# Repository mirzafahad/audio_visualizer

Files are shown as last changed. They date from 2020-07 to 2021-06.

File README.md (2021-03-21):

# RGB LED Backlight and Audio Visualizer



:star: Star me on GitHub — it helps!

A simple WS2812 LED Strip based backlight and audio visualizer using [Adafruit nrf52832 Feather](https://www.adafruit.com/product/3406). You can control the color and modes using an Android App. 

More can be found [here](https://mirzafahad.github.io/2020-07-13-audio-visualizer/).

Backlight in action:  
Backlight in action

Motion Detection:  
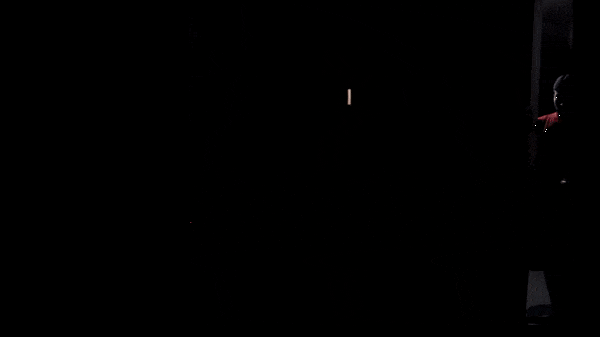
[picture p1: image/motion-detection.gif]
Motion Detection


Android App:  
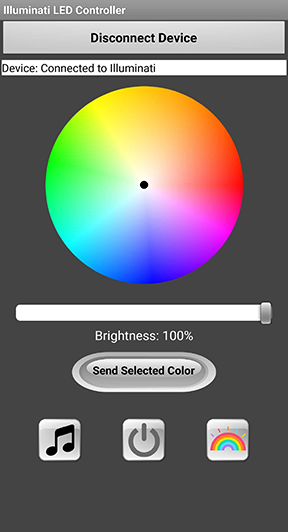
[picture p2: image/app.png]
App Interface


Hardware:  
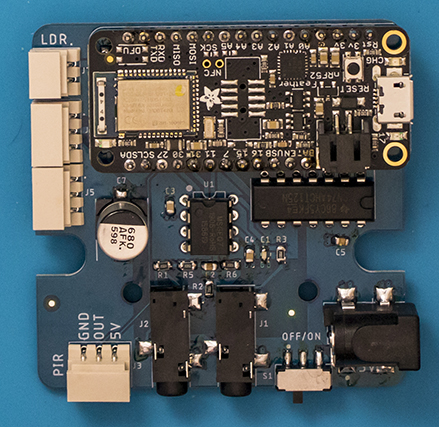
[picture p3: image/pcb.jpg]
Hardware


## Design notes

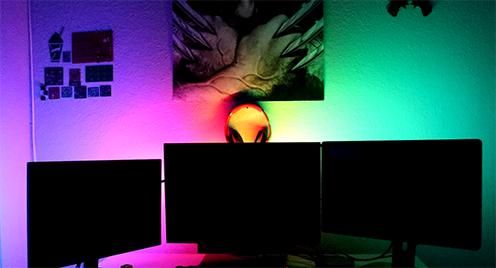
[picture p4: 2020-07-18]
image/demo.png

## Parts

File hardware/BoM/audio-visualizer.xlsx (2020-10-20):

Part | Value | Device | Package | Description
C1 | 33pF | CAP_0805 | CAP_CL21_SAM
C2 | 0.01uF | CAP_0805 | CAP_CL21_SAM
C3 | 1uF | CAP_0805 | CAP_CL21_SAM
C4 | 1uF | CAP_0805 | CAP_CL21_SAM
C5 | 1uF | CAP_0805 | CAP_CL21_SAM
C7 | 680uF | EEE-FK1A681P | CAPAE830X1050N | Cap Aluminum Lytic 680uF 10V 20% (8 X 10.2mm) SMD 600mA 2000h 105C Automotive T/R
J1 | SJ-3523-SMT-TR | SJ-3523-SMT-TR | SJ3523SMTTR | Phone Connectors Audio Jacks
J2 | SJ-3523-SMT-TR | SJ-3523-SMT-TR | SJ3523SMTTR | Phone Connectors Audio Jacks
J3 | 22057035 | 22057035 | 22057035 | Headers & Wire Housings SPOX .098 HDR 03P RA SN"
J4 | 22057035 | 22057035 | 22057035 | Headers & Wire Housings SPOX .098 HDR 03P RA SN"
J5 | 22057035 | 22057035 | 22057035 | Headers & Wire Housings SPOX .098 HDR 03P RA SN"
J6 | PJ-002AH-SMT-TR | PJ-002AH-SMT-TR | CUI_PJ-002AH-SMT-TR | 2.0 mm Center Pin, 5.0 A, Right Angle, Surface Mount (SMT), Dc Power Jack Connector Check prices
J7 | 22-05-7025 | 22-05-7025 | MOLEX_22-05-7025 | Connector Header Through Hole, Right Angle 2 position 0.098in (2.50mm) Buy Part
LOGO1 | OSHW-LOGOL-COPPER | OSHW-LOGOL-COPPER | OSHW-LOGO-L_COPPER | Open-Source Hardware (OSHW) Logo
MS1 | FEATHERWING_JUST_PINS | FEATHERWING_JUST_PINS | FEATHERWING_JUST_PINS
R1 | 10K | R-US_R0805 | R0805 | RESISTOR, American symbol
R2 | 10K | R-US_R0805 | R0805 | RESISTOR, American symbol
R3 | 200K | R-US_R0805 | R0805 | RESISTOR, American symbol
R4 | 330 | R-US_R0805 | R0805 | RESISTOR, American symbol
R5 | 10K | R-US_R0805 | R0805 | RESISTOR, American symbol
R6 | 10K | R-US_R0805 | R0805 | RESISTOR, American symbol
R8 | 10K | R-US_R0805 | R0805 | RESISTOR, American symbol
S1 | JS102011SAQN | JS102011SAQN | JS102011SAQN | C & K COMPONENTS - JS102011SAQN - SWITCH, SPDT, 0.6A, 6VDC, SIDE, SMD
U$2 | FIDUCIAL | FIDUCIAL | FIDUCIAL_1MM | For use by pick and place machines to calibrate the vision/machine, 1mm
U$3 | FIDUCIAL | FIDUCIAL | FIDUCIAL_1MM | For use by pick and place machines to calibrate the vision/machine, 1mm
U$4 | FIDUCIAL | FIDUCIAL | FIDUCIAL_1MM | For use by pick and place machines to calibrate the vision/machine, 1mm
U1 | MSGEQ7P | MSGEQ7DIL | DIP08 | 7-band graphic equalizer
U2 | SN74AHCT125N | SN74AHCT125N | DIP794W53P254L1930H508Q14N | Quadruple Bus Buffer Gates With 3-State Outputs

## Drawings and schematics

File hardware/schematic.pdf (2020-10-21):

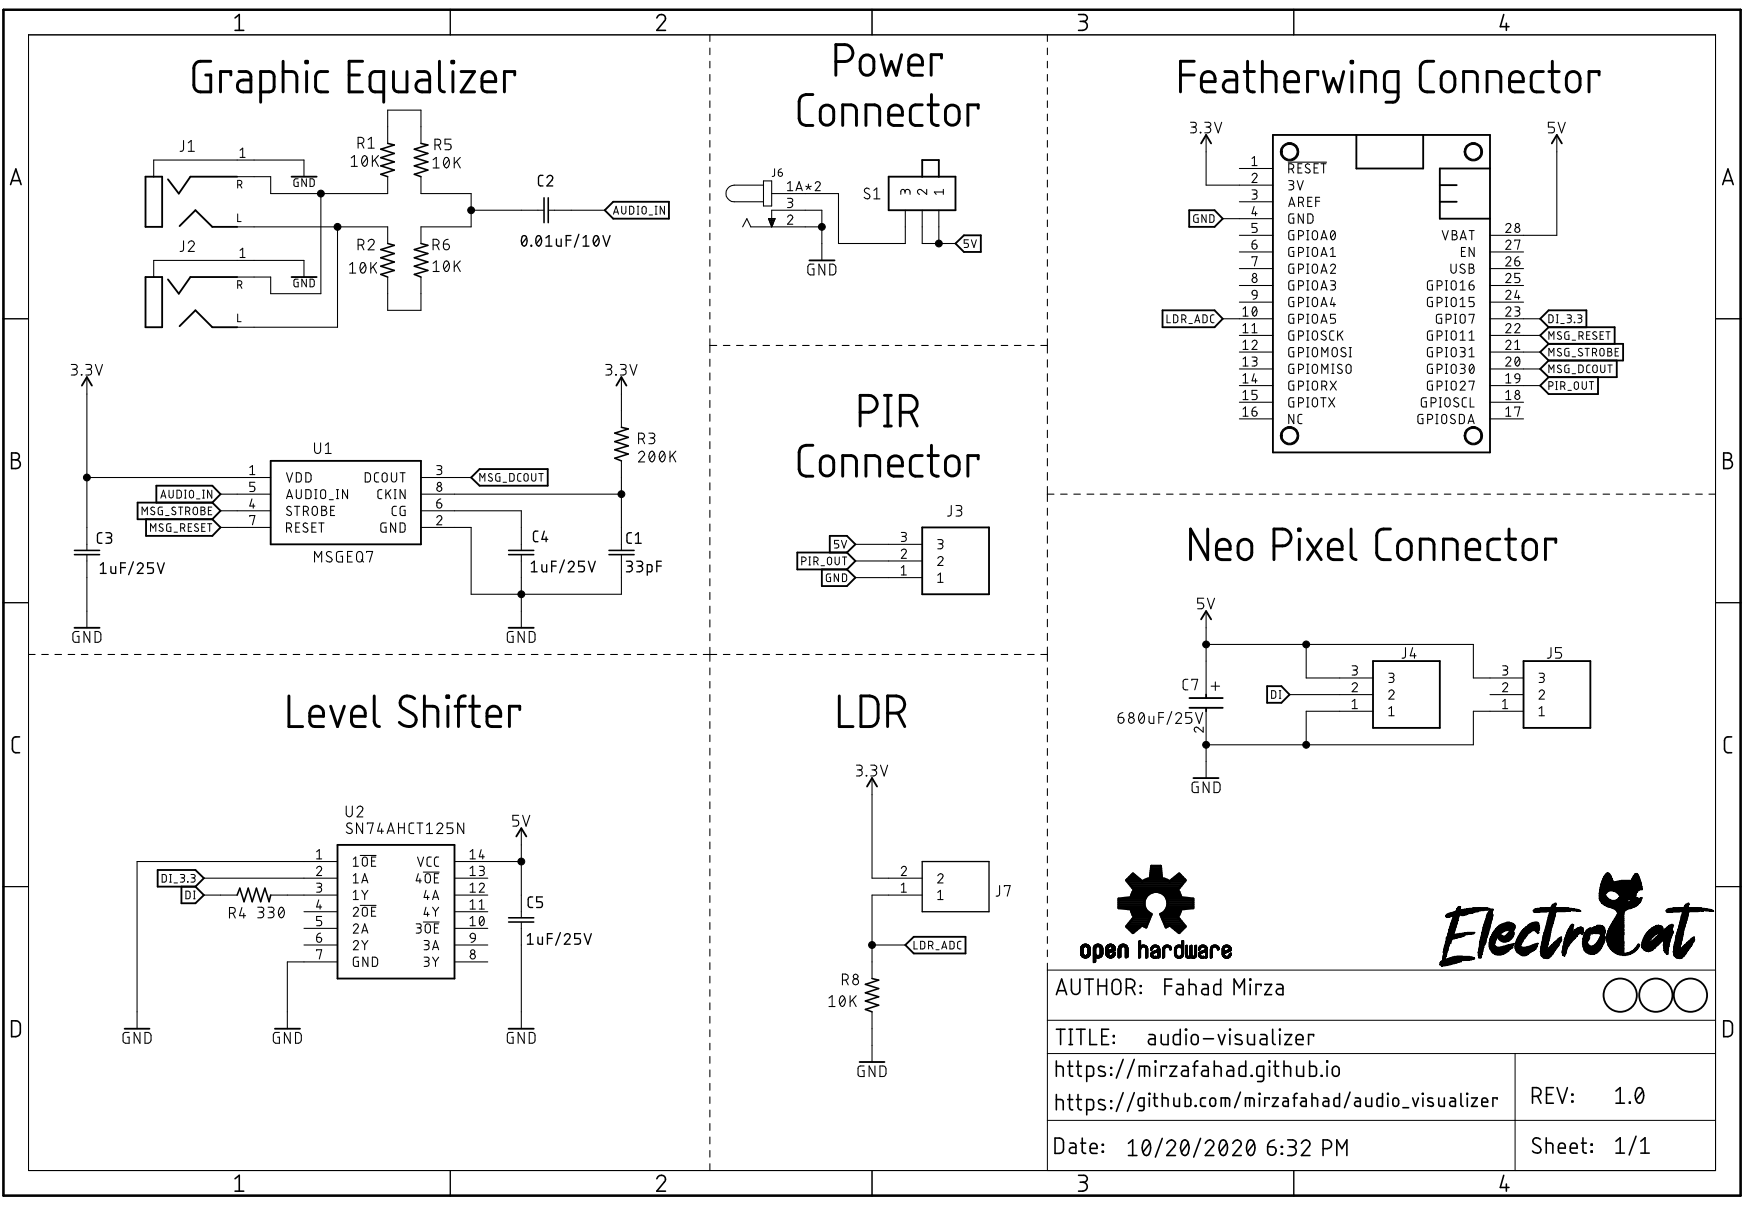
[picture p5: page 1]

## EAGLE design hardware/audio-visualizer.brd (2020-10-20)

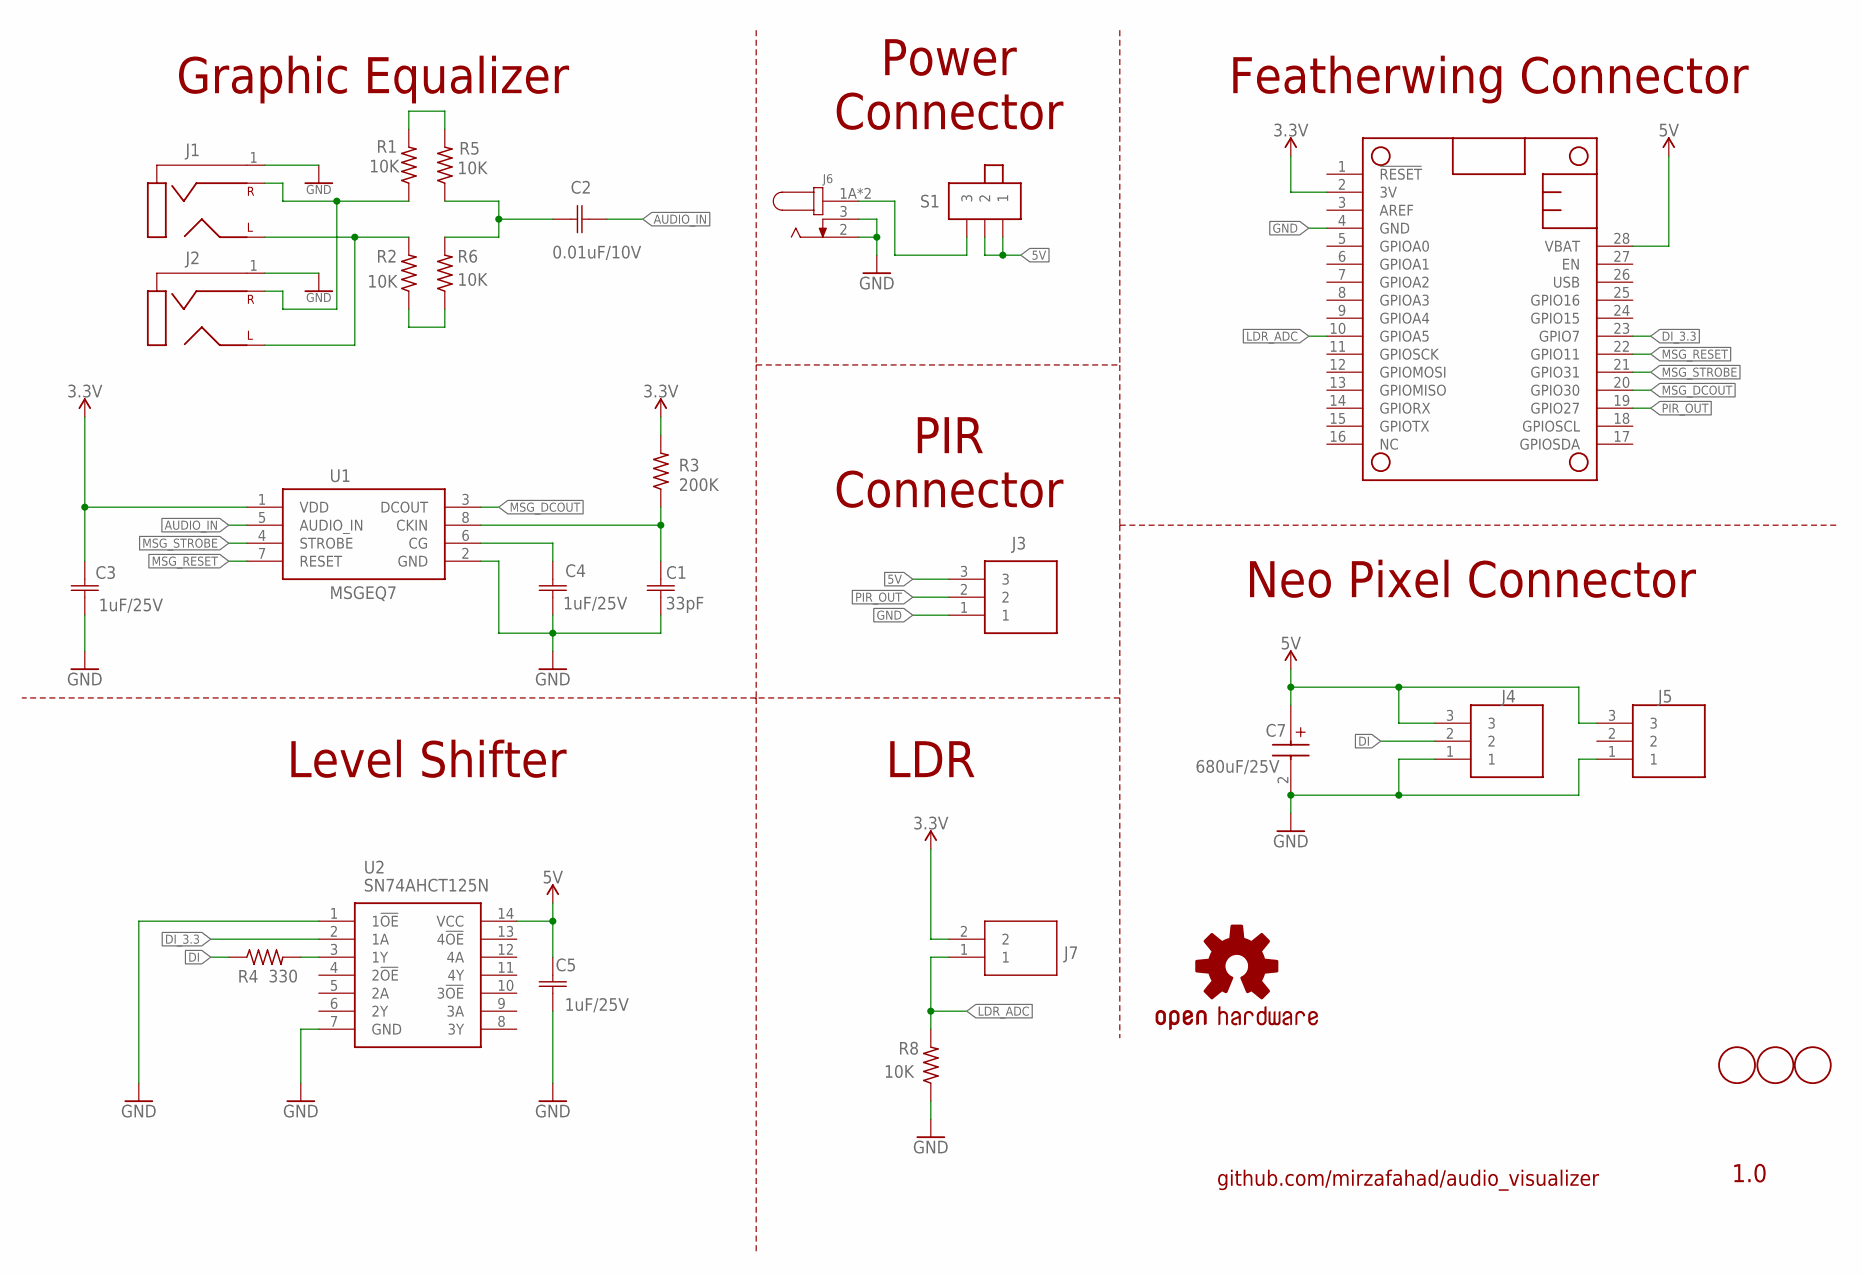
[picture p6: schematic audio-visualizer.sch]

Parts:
C1: 33pF; CAP_CL21_SAM
C2: 0.01uF/10V; CAP_CL21_SAM
C3, C4, C5: 1uF/25V; CAP_CL21_SAM
C7: 680uF/25V; CAPAE830X1050N
J1, J2: SJ-3523-SMT-TR; SJ3523SMTTR
J3, J4, J5: 0022057035
J6: PJ-002AH-SMT-TR; CUI_PJ-002AH-SMT-TR
J7: 22-05-7025; MOLEX_22-05-7025
LOGO1: OSHW-LOGOL-COPPER; OSHW-LOGO-L_COPPER
MS1: FEATHERWING_JUST_PINS
R1, R2, R5, R6, R8: 10K; R0805
R3: 200K; R0805
R4: 330; R0805
S1: JS102011SAQN
U1: MSGEQ7P; DIP08
U2: SN74AHCT125N; DIP794W53P254L1930H508Q14N
U$2, U$3, U$4: FIDUCIAL; FIDUCIAL_1MM

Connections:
3.3V: C3.1, J7.2, MS1.2 (3V), R3.2, U1.1 (VDD)
5V: C5.1, C7.1 (+), J3.3, J4.3, J5.3, MS1.28 (VBAT), S1.1, S1.2, U2.14 (VCC)
AUDIO_IN: C2.2, U1.5 (AUDIO_IN)
DI: J4.2, R4.1
DI_3.3: MS1.23 (GPIO7), U2.2 (1A)
GND: C1.2, C3.2, C4.2, C5.2, C7.2 (-), J1.1, J2.1, J3.1, J4.1, J5.1, J6.2, J6.3, MS1.4 (GND), R8.1, U1.2 (GND), U2.7 (GND)
LDR_ADC: J7.1, MS1.10 (GPIOA5), R8.2
MSG_DCOUT: MS1.20 (GPIO30), U1.3 (DCOUT)
MSG_RESET: MS1.22 (GPIO11), U1.7 (RESET)
MSG_STROBE: MS1.21 (GPIO31), U1.4 (STROBE)
unnamed: R1.2, R5.2
unnamed: R2.1, R6.1
unnamed: C2.1, R5.1, R6.2
unnamed: C1.1, R3.1, U1.8 (CKIN)
unnamed: C4.1, U1.6 (CG)
unnamed: J1.2 (5), J2.2 (5), R2.2
unnamed: R4.2, U2.3 (1Y)
unnamed: J1.3 (2), J2.3 (2), R1.1
unnamed: J6.1A (1), J6.1B (1), S1.3
PIR_OUT: J3.2, MS1.19 (GPIO27)

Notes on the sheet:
Graphic Equalizer
Featherwing Connector
Neo Pixel Connector
Level Shifter
Power Connector
LDR
PIR Connector
1.0
github.com/mirzafahad/audio_visualizer

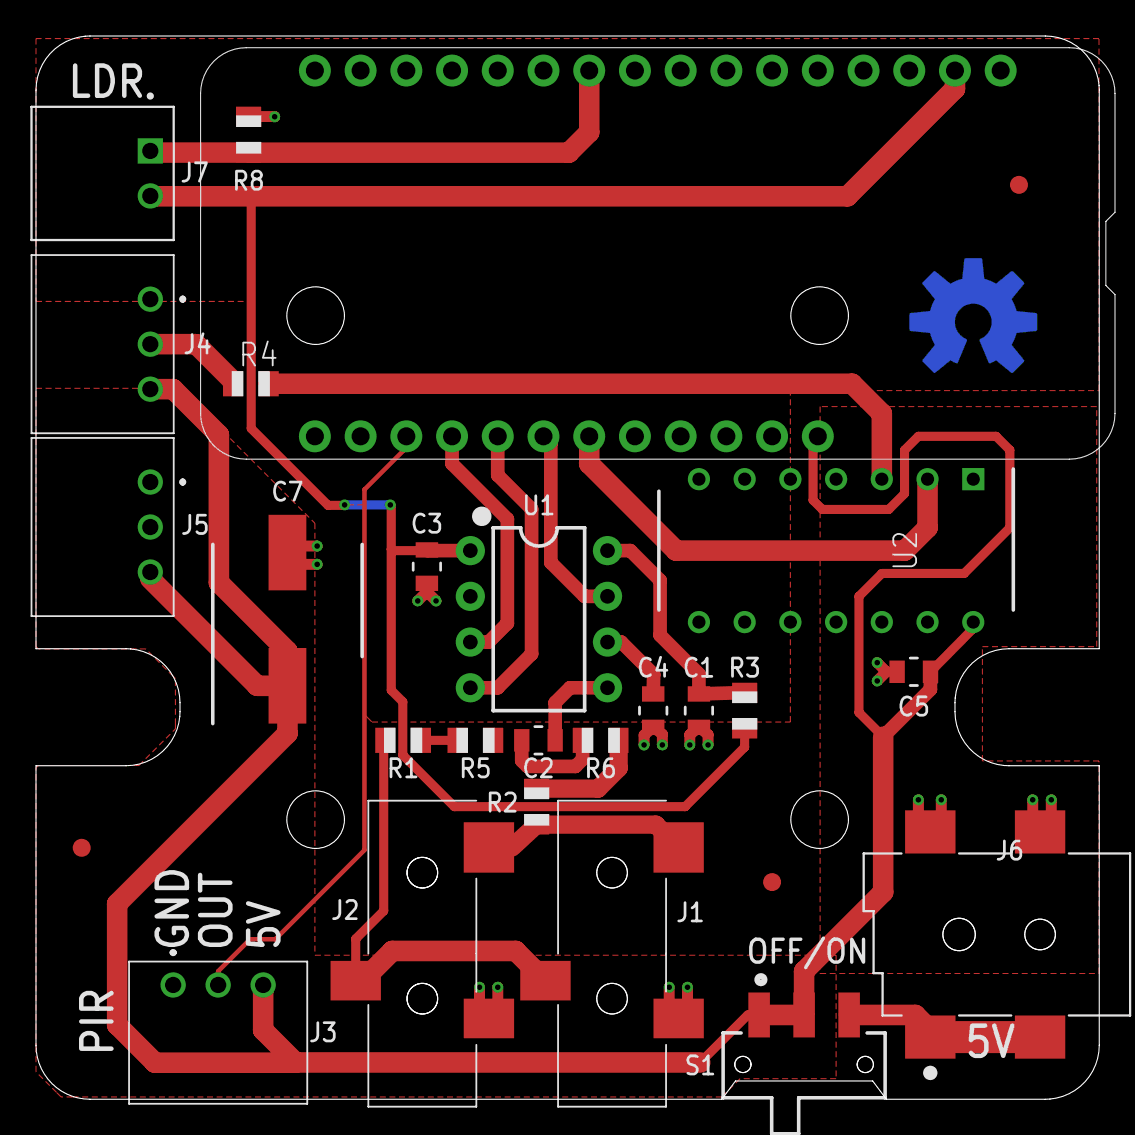
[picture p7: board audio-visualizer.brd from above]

Board: 2 copper layers, 59.1 x 59.1 mm, 28 parts (1 on the bottom side), 20 nets.

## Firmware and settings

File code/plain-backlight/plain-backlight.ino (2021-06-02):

/***********************************************************************
 * @file      audio-visualizer.ino
 * @author    Fahad Mirza (fahadmirza8@gmail.com)
 * @version   V2.0
 * @brief     Main Application
 ***********************************************************************/
/*-- Includes ---------------------------------------------------------*/ 
#include <Arduino.h>
#include <Adafruit_NeoPixel.h>
#include "ble.h"


/*-- Macros -----------------------------------------------------------*/ 
#define CMD_BUFFER_SIZE  (25U)
#define VALID            (1U)
#define INVALID          (0U)
//#define DEBUG


/*-- Constants --------------------------------------------------------*/
static const uint8_t PIN_LDR      = A5;
static const uint8_t PIN_AUDIO_IN = A0;
static const uint8_t PIN_RESET    = 31;
static const uint8_t PIN_STROBE   = 11;
static const uint8_t PIN_NEOPIXEL = 7;
static const uint8_t PIN_PIR      = 27;
static const uint8_t PIN_TV       = A4;

static const uint8_t LED_COUNT    = 108;



/*-- Private typedef --------------------------------------------------*/
typedef enum eMode
{
    POWER_ON = 0,
    POWER_OFF,
    TV_ON,
    RAINBOW,
    BACKLIGHT,
    DARK
}eMode_t;


/*-- Private variables ------------------------------------------------*/
char CmdBuffer[CMD_BUFFER_SIZE + 1];
bool LedIsOn = false;
uint32_t DarkModeCounter = 0;

Adafruit_NeoPixel Neopixel(LED_COUNT, PIN_NEOPIXEL, NEO_GRB + NEO_KHZ800);

// Initial Application Mode
eMode_t AppMode = POWER_OFF;


/*-- Function definitions ---------------------------------------------*/
void setup() 
{
    pinMode(LED_BUILTIN, OUTPUT);
    digitalWrite(LED_BUILTIN, LOW);

    // Config Neopixels
    Neopixel.begin();
    Neopixel.show();              // Turn OFF all LEDs
    Neopixel.setBrightness(255);  // Set BRIGHTNESS to max (max = 255)

    // Config PIR
    pinMode(PIN_PIR, INPUT);
    
    Serial.begin(115200);

#ifdef DEBUG
    // Blocking wait for connection when debug mode is enabled via IDE
    while(!Serial) yield();
#endif

    BLE_Init();
}

void loop() 
{ 
    // Check if there is any command from BLE
    if(BLE_ProcessMsg(CmdBuffer) == VALID)
    {
        parse_cmd(CmdBuffer);
    }

    switch(AppMode)
    {
        case RAINBOW:
        {
            rainbow(20);
            break;
        }
        case DARK:
        {
            if (digitalRead(PIN_PIR) == false)
            {
                delay(1);
                DarkModeCounter++;
                if (DarkModeCounter > 60000)
                {
                    Neopixel.clear();
                    Neopixel.show();
                    LedIsOn = false;
                    DarkModeCounter = 0;
                    AppMode = POWER_OFF;
                    
                    //digitalWrite(LED_BUILTIN, LOW);
                }
            }
            else
            {
                DarkModeCounter = 0;
            }
            break;
        }
        default:
        {
            // Backlight doesn't need continuous execution
            break;
        }
    }

    //Serial.printf("P:%d\tD:%ld\n", digitalRead(PIN_PIR), DarkModeCounter);

    if ((digitalRead(PIN_PIR) == true) && (LedIsOn == false) && (read_ldr() <= 30))
    {
        Neopixel.setBrightness(255);
        Neopixel.fill(Neopixel.Color(255, 170, 40));
        Neopixel.show();
        LedIsOn = true;
        AppMode = DARK;
        DarkModeCounter = 0;

        //digitalWrite(LED_BUILTIN, HIGH);
    }

    if (is_tv_on() && (LedIsOn == false))
    {
        backlight(0); // Whatever last was used
        LedIsOn = true;
        AppMode = TV_ON;
    }
    else if ((is_tv_on() == false) && (AppMode == TV_ON))
    {
        Neopixel.clear();
        Neopixel.show();
        LedIsOn = false;
        AppMode = POWER_OFF;
    }

}

bool is_tv_on(void)
{
    if (analogRead(PIN_TV) > 400)
    {
        return true;
    }

    return false;
}

uint32_t read_ldr(void)
{
    uint32_t sensorValueSum = 0;

    for(int i = 0; i < 50; i++)
    {    
        sensorValueSum += analogRead(PIN_LDR);
    }
    
    uint32_t sensorValueAvg = sensorValueSum / 50;

    //Serial.println(sensorValueAvg);
    
    return sensorValueAvg;
}


/******************************************************************************
 * @brief  parse the command received from BLE
 * @param  cmd: pointer of the buffer that holds the command
 * @retval None
 ******************************************************************************/
static void parse_cmd(char *cmd)
{
    if(strncmp(cmd, "pwroff", strlen("pwroff")) == 0)
    {
        Neopixel.clear();
        Neopixel.show();
        LedIsOn = false;
        AppMode = POWER_OFF;
    }
    else if(strncmp(cmd, "pwron", strlen("pwron")) == 0)
    {
        backlight(0); // Whatever last was used
        LedIsOn = true;
        AppMode = POWER_ON;
    }
    else if(strncmp(cmd, "rainbow", strlen("rainbow")) == 0)
    {
        Neopixel.setBrightness(255);
        LedIsOn = true;
        AppMode = RAINBOW;
    }
    else if(strncmp(cmd, "bl", strlen("bl")) == 0)
    {
        // BackLight mode. The command looks like this
        // "bl,253,124,78,100" (cmd,r,g,b,brightness)

        // Skip "bl,"
        cmd += 3;
        
        char *token;
        char rgb[5];   // Holder for RGB and brightness
        uint8_t i = 0;

        token = strtok(cmd, ",");
        while(token != NULL)
        {
            rgb[i++] = strtol(token, NULL, 10);
            token = strtok(NULL, ",");
        }
        
        Neopixel.setBrightness(rgb[3]);
        backlight(Neopixel.Color(rgb[0], rgb[1], rgb[2]));
        LedIsOn = true;

        if (AppMode != TV_ON)
        {
            AppMode = BACKLIGHT;
        }
    }
}


/******************************************************************************
 * @brief  Turn ON all the LED with one color
 * @param  32bit color value
 * @retval None
 ******************************************************************************/
void backlight(uint32_t color)
{
    // This value is static. So if we press "power on" it will use
    // whatever color was last used as backlight.
    static uint32_t backlightColor = Neopixel.Color(0, 0, 255);

    if(color != 0)
    {
        backlightColor = color;
    }
    Neopixel.fill(backlightColor);
    Neopixel.show();
}


/******************************************************************************
 * @brief  Execute the rainbow animation on the LED strip
 * @param  wait: how long to wait between color transition
 * @retval None
 ******************************************************************************/
// Rainbow cycle along whole strip. Pass delay time (in ms) between frames.
void rainbow(int wait) 
{
    static long firstPixelHue = 0;

    for(uint8_t i = 0; i < Neopixel.numPixels(); i++) 
    {
      // Offset pixel hue by an amount to make one full revolution of the
      // color wheel (range of 65536) along the length of the strip
      // (strip.numPixels() steps):
      int pixelHue = firstPixelHue + (i * 65536L / Neopixel.numPixels());
      // strip.ColorHSV() can take 1 or 3 arguments: a hue (0 to 65535) or
      // optionally add saturation and value (brightness) (each 0 to 255).
      // Here we're using just the single-argument hue variant. The result
      // is passed through strip.gamma32() to provide 'truer' colors
      // before assigning to each pixel:
      Neopixel.setPixelColor(i, Neopixel.gamma32(Neopixel.ColorHSV(pixelHue)));
    }
    
    Neopixel.show(); // Update strip with new contents
    delay(wait);     // Pause for a moment

    firstPixelHue += 256;

    if(firstPixelHue >= 5*65536)
    {
        firstPixelHue = 0;
    }
}

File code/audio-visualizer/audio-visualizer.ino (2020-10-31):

/***********************************************************************
 * @file     audio-visualizer.ino
 * @author   Fahad Mirza (fahadmirza8@gmail.com)
 * @version  V2.0
 * @brief    Main Application
 ***********************************************************************/
/*-- Includes ---------------------------------------------------------*/ 
#include <Arduino.h>
#include <Adafruit_NeoPixel.h>
#include "ble.h"


/*-- Macros -----------------------------------------------------------*/ 
#define BLE_MSG_BUF_SIZE (25U)
#define VALID            (1U)
#define INVALID          (0U)


/*-- Constants --------------------------------------------------------*/
static const uint8_t PIN_AUDIO_IN = A0;
static const uint8_t PIN_RESET    = 31;
static const uint8_t PIN_STROBE   = 11;
static const uint8_t PIN_NEOPIXEL = 7;
static const uint8_t LED_COUNT    = 84;
static const char* DEVICE_NAME    = "Illuminati";


/*-- Private typedef --------------------------------------------------*/
typedef enum eMode
{
    MUSIC = 0,
    POWER_ON,
    POWER_OFF,
    RAINBOW,
    BACKLIGHT
}eMode_t;


/*-- Private variables ------------------------------------------------*/
// Save all 7 bands value
static uint32_t Bands[7];
static char BleBuf[BLE_MSG_BUF_SIZE + 1];

// Initial Application Mode
eMode_t AppMode = POWER_OFF;

Adafruit_NeoPixel Neopixel(LED_COUNT, PIN_NEOPIXEL, NEO_GRB + NEO_KHZ800);


/*-- Function definitions ---------------------------------------------*/
void setup() 
{
    // Config MSGEQ7
    pinMode(PIN_RESET, OUTPUT);
    digitalWrite(PIN_RESET, LOW);
    
    pinMode(PIN_STROBE, OUTPUT);
    digitalWrite(PIN_STROBE, HIGH);

    pinMode(LED_BUILTIN, OUTPUT);
    digitalWrite(LED_BUILTIN, HIGH);

    // Config Neopixels
    Neopixel.begin();
    Neopixel.show();              // Turn OFF all LEDs
    Neopixel.setBrightness(255);  // Set BRIGHTNESS to max (max = 255)
    
    Serial.begin(9600);

#ifdef DEBUG
    // Blocking wait for connection when debug mode is enabled via IDE
    while (!Serial)
    {
        yield();
    }
#endif

    // Initialize BLE with the specified device name
    BLE_init(DEVICE_NAME);
}


void loop() 
{ 
    // Check if there is any message from BLE
    if(BLE_process_msg(BleBuf) == VALID)
    {
        parse_msg(BleBuf);
    }

    // Execute whatever application mode is set
    switch(AppMode)
    {
        case MUSIC:
        {
            // Get the spectrum value of the audio from audio input
            // and animate LEDs accordingly
            audio_visualizer();
            break;
        }
        case RAINBOW:
        {
            // Run the rainbow animation
            rainbow(20);
            break;
        }
        default:
        {
            // Backlight doesn't need continuous execution
            break;
        }
    }
}


/******************************************************************************
 * @brief  Parse the message received from BLE
 * @param  msg: pointer of the buffer that holds the message
 * @retval None
 ******************************************************************************/
static void parse_msg(char *msg)
{
    if (strncmp(msg, "music", strlen("music")) == 0)
    {
        Neopixel.setBrightness(255);
        AppMode = MUSIC;
    }
    else if (strncmp(msg, "pwroff", strlen("pwroff")) == 0)
    {
        Neopixel.clear();
        Neopixel.show();
        AppMode = POWER_OFF;
    }
    else if (strncmp(msg, "pwron", strlen("pwron")) == 0)
    {
        backlight(0); // Whatever color was used last
        AppMode = POWER_ON;
    }
    else if (strncmp(msg, "rainbow", strlen("rainbow")) == 0)
    {
        Neopixel.setBrightness(255);
        AppMode = RAINBOW;
    }
    else if (strncmp(msg, "bl", strlen("bl")) == 0)
    {
        // BackLight mode. The message looks like this:
        // "bl,253,124,78,100" (msg,r,g,b,brightness)

        // Skip "bl,"
        msg += 3;
        
        char *token;
        char rgb[5];   // Holder for RGB and brightness
        uint8_t i = 0;

        token = strtok(msg, ",");
        while (token != NULL)
        {
            rgb[i++] = strtol(token, NULL, 10);
            token = strtok(NULL, ",");
        }
        
        Neopixel.setBrightness(rgb[3]);
        backlight(Neopixel.Color(rgb[0], rgb[1], rgb[2]));
        AppMode = BACKLIGHT;
    }
}


/******************************************************************************
 * @brief  Turn ON all the LEDs with one color
 * @param  color: 32bit color value
 * @retval None
 ******************************************************************************/
void backlight(uint32_t color)
{
    // This value is static. So if we press "power on" it will use
    // whatever color was last used as backlight.
    static uint32_t backlightColor = Neopixel.Color(255, 255, 255);

    if (color != 0)
    {
        backlightColor = color;
    }
    Neopixel.fill(backlightColor);
    Neopixel.show();
}


/******************************************************************************
 * @brief  Display audio spectrum on LED strip
 * @param  None
 * @retval None
 ******************************************************************************/
static void audio_visualizer(void)
{
    read_MSGEQ7(); 
    graph_bands();
}


/******************************************************************************
 * @brief  Read MSGEQ7 and populate the global array
 * @param  None
 * @retval None
 ******************************************************************************/
static void read_MSGEQ7(void)
{
    digitalWrite(PIN_RESET, HIGH);           // Pulse the reset signal
    digitalWrite(PIN_RESET, LOW);            // Causes MSGEQ7 to latch spectrum values
    delayMicroseconds(75);                   // Delay to meet min reset-to-strobe time (72us)

    for (uint8_t i = 0; i < 7; i++)          // Cycle through all 7 bands
    {
        digitalWrite(PIN_STROBE, LOW);        
        delayMicroseconds(40);               // Wait for output to settle (min 36us)
        Bands[i] = analogRead(PIN_AUDIO_IN);

        digitalWrite(PIN_STROBE, HIGH);
        delayMicroseconds(40);               // Pad delay to exceed min strobe-to-strobe time of 72us
    }
}
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

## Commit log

2020-08-13 Added schematic.
    [audio-visualizer.sch]
2020-08-13 pdf schematic added.
    [audio-visualizer.sch]
2020-10-20 Updated folder structures.
    [audio-visualizer.brd, audio-visualizer.sch, audio-visualizer.xlsx]
2020-10-21 Schematic PDF is added.
2021-06-02 Now the backlight turns ON when the TV is turned ON and turns OFF when the TV is turned OFF. When the TV is turned ON the USB ports of the TV gets power. That is fed to an ADC after a voltage divider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
    [audio-visualizer.brd, audio-visualizer.sch, audio-visualizer.xlsx]
2021-06-02 Incresed the LED numbers to cover more area. Not doing audio spectrum for the TV backlight. During dark times (!) the light will stay on for longer (30s to 1min). Changed the default color to Blue fr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

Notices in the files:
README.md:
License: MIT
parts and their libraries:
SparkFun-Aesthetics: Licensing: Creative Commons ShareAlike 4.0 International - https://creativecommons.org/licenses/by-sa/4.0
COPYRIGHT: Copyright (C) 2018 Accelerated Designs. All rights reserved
